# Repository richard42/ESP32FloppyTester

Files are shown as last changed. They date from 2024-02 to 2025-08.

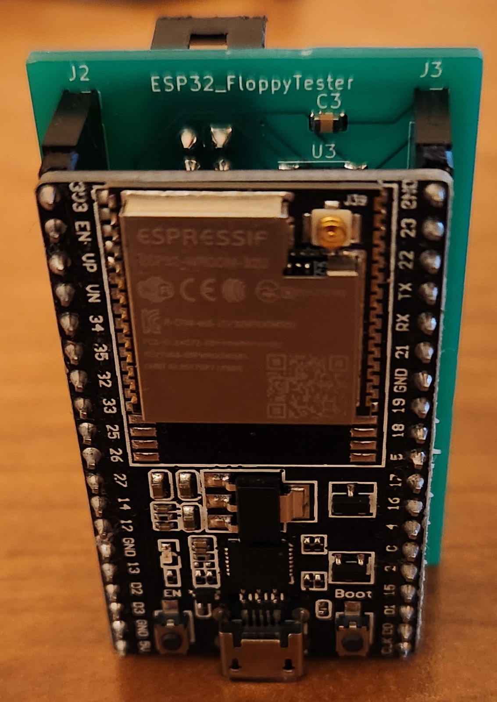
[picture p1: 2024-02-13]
doc/pic-assembled-with-esp32.jpg

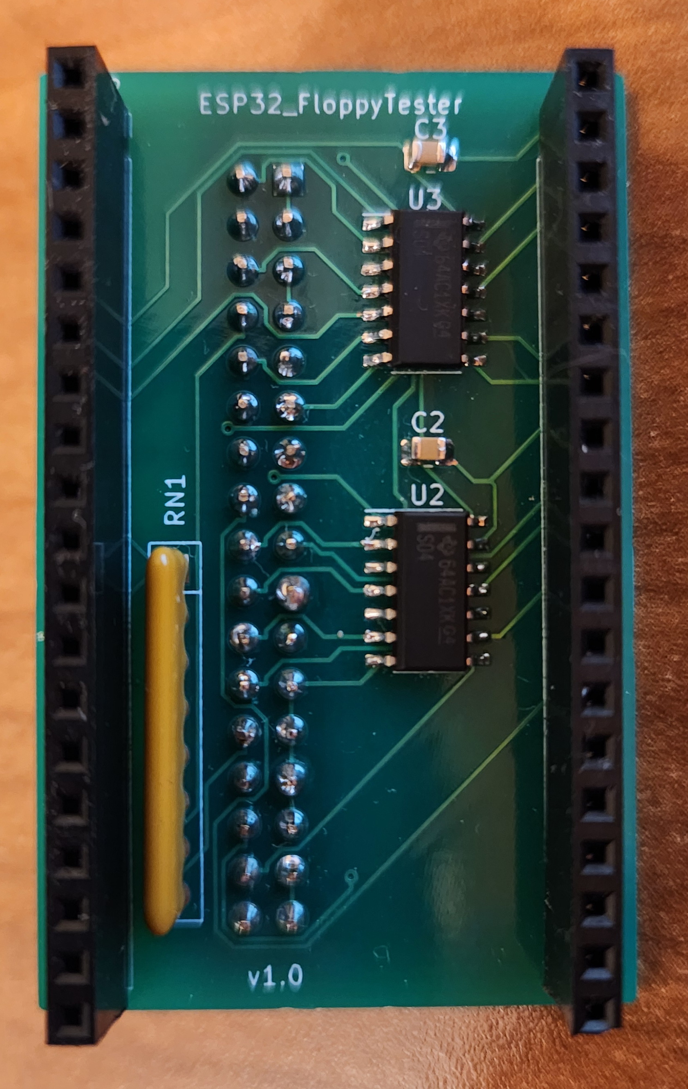
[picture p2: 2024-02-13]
doc/pic-board-front.jpg

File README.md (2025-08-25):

# ESP32_FloppyTester README

## What it is

The ESP32_FloppyTester is an open-source hardware/software project which aims to create a software-based floppy drive controller and tester with very low-cost hardware.  The materials cost for the interface board is under 10 dollars, and aside from a floppy drive cable the only other part necessary is an ESP32 development board, which can also be had for under 10 dollars.

The user communicates with the ESP32_FloppyTester via a serial monitor program on a PC or laptop, connected to the ESP32 development board by a USB cable.

The user gives commands to the ESP32_FloppyTester through the serial terminal, and as the desired operations are performed, statistics and results are sent back to the user.

The focus of this project is creating an easily-hackable tool which can be used in the diagnosis and repair of vintage 3.5" and 5.25" floppy drives.

## What it is NOT

The ESP32_FloppyTester is not designed to read or write disk image files for copying or preservation of digital media.  There are numerous projects already available which serve this function well.  Before creating the ESP32_FloppyTester, I purchased and used the KryoFlux, the FluxEngine, and the GreaseWeazle. These are all very capable products for recording and capturing data from floppy drives.

The focus of this project is to give the user very low-level control over the operation of a floppy drive so that if it is defective, the nature and root cause of the defect(s) may be determined and remedied.

## Contents

* [Hardware Warning](#hardware-warning)
* [Setup](#setup)
* [Basic Usage](#basic-usage)
* [Advanced Usage](#advanced-usage)
* [Caveats](caveats)

### Hardware Warning

There is one important flaw with the current interface board design, and users must be aware of this.

When the ESP32 microcontroller is being flashed by the ESP-IDF development system, all of its pins go into a high-impedance state with pull-up resistors.

As a result, all of the output lines will go active on any connected floppy drive. In particular, the SELECT, MOTOR ON, SIDE 1, and WRITE GATE lines will all be active during the ESP32 flashing process.

Because of this, if there is a disk inserted into the connected floppy drive, and it is not write protected, the track on side 1 which is under the drive head will be erased.

As a workaround, the user should always make sure that the drive has no disk in it when re-flashing the ESP32 software.

### Setup

To build the interface board, you may send the Gerber files in the "hardware" sub-directory to a printed-circuit board manufacturer such as PCBWay or JLCPCB. Order the remaining parts from digi-key and solder the board together once it all arrives. The "doc" sub-folder contains a Bill of Materials and pictures of the finished product.

The next step is to set up the [arduino IDE software](https://www.arduino.cc/en/software) and configure it for your ESP32 board. Then just load up the ESP32_FloppyTest.ino source code in your Arduino IDE and click the "Upload" button to compile the code and flash the ESP32 device. (But make sure there is no floppy disk in the drive, if you have one connected!)

Before connecting a drive the first time, it is good to check your soldering with the `TEST INPUT` and `TEST OUTPUT` commands.

When in the `TEST INPUT` mode, the software will poll for changes on any input pins and print the names and states of the pins when they change. You may use a jumper wire to bridge each input pin to a 5-volt supply, and observe the change via the serial monitor.

In the `TEST OUTPUT` mode, each output pin will oscillate with a binary pattern corresponding to the number of the pin. This pattern may be observed by connecting an oscilloscope to each output pin in turn. This test mode should never be used when a floppy drive is connected to the 34-pin connector, or **bad** things may happen.

Either test mode may be exited by sending a blank line or any characters to the ESP32.

### Basic Usage

Use the `HELP` command to view a list of all supported commands.

The floppy drive hardware interface, though common across many different drives and vintage computer systems, uses 5 different pins for selecting a particular drive and turning on its motor. The software currently defaults to a *shugart*-style interface with drive 0, such as would be configured for an internal drive on an Amiga computer. PC/Atari drives use different pins for drive selection, and so the user must use the `DETECT PINS` command to set the correct pins before anything else will work.

The `DETECT PINS` command activates each pin individually, and requests feedback from the user based upon how it affects the status of the floppy drive. At each step, the user must tell the ESP32_FloppyTester if the drive light has been illuminated, or if the motor has been activated. After answering all 5 prompts, the software will configure itself to properly address your floppy drive, and all of the other commands should then work.  If the detection fails and the drive light or motor never comes on, this indicates a failure in the drive's selection or motor control circuitry.

The next diagnostic step is to use the `DETECT RPM` command. A floppy disk must be inserted for this to work.  This command will enable the motor and begin sampling the INDEX pin, printing out the current drive RPM speed once per second. If this command fails, it indicates a problem with the index hole detection circuitry, or no floppy disk in the drive.

The final basic drive test can be performed with the `SEEK TEST` command. This will cause the drive to seek outwards until the TRACK0 line goes active, and then seek back and forth several times and ensure that track 0 is reached each time after returning there. If this command fails, there is likely to be a problem with the stepper motor drive circuitry or the track 0 detection mechanism.

### Advanced Usage

After all of the basic drive tests have passed, the user can move on to more advanced testing. The full command list is as follows:

```    HELP           - display this help message.
    TEST INPUT     - activate input test mode, and print level changes on input lines.
    TEST OUTPUT    - activate output test mode, and drive output pins with binary pin numbers.
    DETECT PINS    - toggle select lines to determine drive wiring/jumper setup.
    DETECT RPM     - spin up motor and calculate spindle speed from index pulses.
    DETECT STATUS  - show status of Track0, Write Protect, and Disk Change signal.
    MOTOR ON/OFF   - activate or de-activate motor 1
    SEEK HOME      - move to track 0.
    SEEK TEST      - test head seeking and track 0 detection.
    SEEK <X>       - seek head to track X.
    SEEK           - display current track number.
    SIDE <X>       - use side X (0 or 1) for single-sided commands.
    SIDE           - display current side number.
    GEOMETRY ...   - set/show current disk format and geometry. Examples:
             IBM   <SS/DS> <X> <Y> - set IBM format, single/double sided, X tracks, Y sectors.
             ATARI <SS/DS> <X> <Y> - set Atari format, single/double sided, X tracks, Y sectors.
             AMIGA                 - set Amiga format, 2 sides, 80 tracks, 11 sectors.
             COMMODORE             - set Commodore format, 1 side, 35 tracks, 17-21 sectors.
    TRACK READ     - read current track and print decoded data summary (requires formatted disk).
    TRACK ERASE    - erase current track and validate erasure (destroys data on disk).
    TRACK WRITE ...- write track data with current format and given pattern (destroys data on disk).
                ZEROS     - all sector data is binary 0 (MFM 4us intervals).
                ONES      - all sector data is binary 1 (MFM 4us intervals).
                SIXES     - all sector data is alternating bits (MFM 6us intervals).
                EIGHTS    - all sector data is alternating bits (MFM 8us intervals).
                RANDOM    - all sector data is random.
    TRACK RWTEST   - write and verify current track with 4 different patterns (destroys data on disk).\r\n");
    DISK READ      - read all tracks on disk and display track/sector status.
    DISK ERASE     - erase all tracks on the disk (destroys data on disk).
    DISK WRITE ... - write all tracks on disk with current format and given pattern (destroys data on disk).
    DISK RWTEST    - write and verify all tracks on disk with 4 different patterns (destroys data on disk).
```
#### DETECT STATUS
The `DETECT STATUS` command may be used to read the state of 3 input lines, which can indicate if the write protect switch/LED and the disk change circuitry (if supported by the drive) is working.

#### MOTOR ON
The user may activate the motor using the `MOTOR ON` command, and then the other commands will leave the motor running after they complete. This could be useful if a particular drive takes longer than the specified 0.5 seconds to settle after motor startup.

#### TRACK READ
The `TRACK READ` command captures the disk pulses from one revolution at the current head position, generates some statistics about the pulse timing intervals, and tries to decode any sector data found. This command is affected by the current drive geometry. The drive geometry must be set to "amiga" if reading amiga disks, or the default IBM if reading IBM or Atari ST disks. The output from the `TRACK READ` command looks like this:

```Track read complete; recorded 37967 flux transitions.
90% pulse interval spread is 0.7 microseconds.
Pulse Distance  Count   Average   Variance
     000004 us  18596   3.981 us  0.00324 us
     000005 us      1   4.988 us  0.00000 us
     000006 us  14598   6.025 us  0.00341 us
     000007 us      1   7.012 us  0.00000 us
     000008 us   4769   8.012 us  0.00459 us
     000030 us      1   29.712 us  0.00000 us
Double Density MFM track detected.
Found Index Access Marker (track start).
IBM Sector ID: Cylinder 0, Side 0, Sector 1, CRC=ca6f (GOOD)
IBM Sector data: 512 bytes with CRC=3cde (GOOD)
IBM Sector ID: Cylinder 0, Side 0, Sector 2, CRC=9f3c (GOOD)
IBM Sector data: 512 bytes with CRC=0f18 (GOOD)
IBM Sector ID: Cylinder 0, Side 0, Sector 3, CRC=ac0d (GOOD)
IBM Sector data: 512 bytes with CRC=b1b1 (GOOD)
IBM Sector ID: Cylinder 0, Side 0, Sector 4, CRC=359a (GOOD)
IBM Sector data: 512 bytes with CRC=0751 (GOOD)
IBM Sector ID: Cylinder 0, Side 0, Sector 5, CRC=06ab (GOOD)
IBM Sector data: 512 bytes with CRC=e9f6 (GOOD)
IBM Sector ID: Cylinder 0, Side 0, Sector 6, CRC=53f8 (GOOD)
IBM Sector data: 512 bytes with CRC=bb59 (GOOD)
IBM Sector ID: Cylinder 0, Side 0, Sector 7, CRC=60c9 (GOOD)
IBM Sector data: 512 bytes with CRC=320e (GOOD)
IBM Sector ID: Cylinder 0, Side 0, Sector 8, CRC=70f7 (GOOD)
IBM Sector data: 512 bytes with CRC=6da6 (GOOD)
IBM Sector ID: Cylinder 0, Side 0, Sector 9, CRC=43c6 (GOOD)
IBM Sector data: 512 bytes with CRC=ff82 (GOOD)
9 IBM sectors read.
```

The first line tells the total number of pulses received (flux transitions detected) during the track read. Normally, with a 720k disk this will be in the range of 15,000 to 40,000.  The data is encoded on the floppy disk by varying the time between adjacent pulses. For an MFM-encoded double-density disks, nearly all of the pulses should be either 4, 6, or 8 microseconds apart.

The "pulse interval spread" is a statistical metric which tells us how much variation exists between the pulse timings. For a formatted disk with data written along the entire track, this value will be in the 0.5-1.5 microsecond range. For a track which has been completely erased, this value will be much higher, in the 9-10 microsecond range.

Next, a histogram tells us how many pulse intervals fell into each 1-microsecond range. Again with an MFM-formatted double-density disk, we expect to see the vast majority of the pulse intervals at 4, 6, and 8 microseconds and very few in the other time ranges.

After the histogram, any decoded sector data will be printed. If you expect to see track information here, but there's nothing, and the histogram looks good, make sure that you have set the correct encoding format (IBM/Amiga) with the `GEOMETRY` command.

#### DISK READ
Using the `DISK READ` command, you can get an overview of all the sectors on the disk.  The output looks like this:

```Command> DISK READ
Found track 0 after stepping 0.0 tracks.
Reading disk sides 0 and 1.
 0 (37964 0.7) MFM  9 Sectors: OOO OOO OOO OOO OOO OOO OOO OOO OOO  |  (37911 0.7) MFM  8 Sectors: --- OOO OOO OOO OOO OOO OOO OOO OOO 
 1 (38001 0.7) MFM  8 Sectors: --- OOO OOO OOO OOO OOO OOO OOO OOO  |  (37859 0.7) MFM  8 Sectors: --- OOO OOO OOO OOO OOO OOO OOO OOO 
 2 (37856 0.7) MFM  8 Sectors: --- OOO OOO OOO OOO OOO OOO OOO OOO  |  (37846 0.7) MFM  8 Sectors: --- OOO OOO OOO OOO OOO OOO OOO OOO 
 3 (37896 0.7) MFM  8 Sectors: --- OOO OOO OOO OOO OOO OOO OOO OOO  |  (38010 0.7) MFM  8 Sectors: --- OOO OOO OOO OOO OOO OOO OOO OOO 
 4 (37953 0.7) MFM  8 Sectors: --- OOO OOO OOO OOO OOO OOO OOO OOO  |  (37851 0.7) MFM  8 Sectors: --- OOO OOO OOO OOO OOO OOO OOO OOO 
 5 (37913 0.7) MFM  8 Sectors: --- OOO OOO OOO OOO OOO OOO OOO OOO  |  (37917 0.7) MFM  8 Sectors: --- OOO OOO OOO OOO OOO OOO OOO OOO 
 6 (37851 0.7) MFM  8 Sectors: --- OOO OOO OOO OOO OOO OOO OOO OOO  |  (37865 0.7) MFM  8 Sectors: --- OOO OOO OOO OOO OOO OOO OOO OOO 
 7 (37896 0.7) MFM  8 Sectors: --- OOO OOO OOO OOO OOO OOO OOO OOO  |  (37998 0.7) MFM  8 Sectors: --- OOO OOO OOO OOO OOO OOO OOO OOO 
 8 (37863 0.7) MFM  8 Sectors: --- OOO OOO OOO OOO OOO OOO OOO OOO  |  (37900 0.7) MFM  8 Sectors: --- OOO OOO OOO OOO OOO OOO OOO OOO 
 9 (37843 0.7) MFM  8 Sectors: --- OOO OOO OOO OOO OOO OOO OOO OOO  |  (37952 0.7) MFM  8 Sectors: --- OOO OOO OOO OOO OOO OOO OOO OOO 
10 (37921 0.7) MFM  8 Sectors: --- OOO OOO OOO OOO OOO OOO OOO OOO  |  (37926 0.7) MFM  8 Sectors: --- OOO OOO OOO OOO OOO OOO OOO OOO 
11 (37910 0.7) MFM  8 Sectors: --- OOO OOO OOO OOO OOO OOO OOO OOO  |  (37894 0.7) MFM  8 Sectors: --- OOO OOO OOO OOO OOO OOO OOO OOO 
12 (37892 0.7) MFM  8 Sectors: --- OOO OOO OOO OOO OOO OOO OOO OOO  |  (37912 0.7) MFM  8 Sectors: --- OOO OOO OOO OOO OOO OOO OOO OOO 
13 (37958 0.7) MFM  8 Sectors: --- OOO OOO OOO OOO OOO OOO OOO OOO  |  (37955 0.7) MFM  8 Sectors: --- OOO OOO OOO OOO OOO OOO OOO OOO 
14 (37951 0.7) MFM  8 Sectors: --- OOO OOO OOO OOO OOO OOO OOO OOO  |  (37939 0.7) MFM  8 Sectors: --- OOO OOO OOO OOO OOO OOO OOO OOO 
15 (37899 0.7) MFM  8 Sectors: --- OOO OOO OOO OOO OOO OOO OOO OOO  |  (37882 0.7) MFM  8 Sectors: --- OOO OOO OOO OOO OOO OOO OOO OOO 
16 (37934 0.7) MFM  8 Sectors: --- OOO OOO OOO OOO OOO OOO OOO OOO  |  (37857 0.7) MFM  8 Sectors: --- OOO OOO OOO OOO OOO OOO OOO OOO 
17 (18787 10.7) MFM  0 Sectors: --- --- --- --- --- --- --- --- ---  |  (37892 2.8) MFM  0 Sectors: --- --- --- --- --- --- --- --- --- 
18 (34117 3.7) MFM  0 Sectors: --- --- --- --- --- --- --- --- ---  |  (36187 2.9) MFM  0 Sectors: --- --- --- --- --- --- --- --- --- 
```

The left half of this shows side 0, while the right half shows side 1.  At the start of each track, in parentheses, are the values for the number of flux transitions in the track, and the 90% pulse interval spread statistic.

Following this is the encoding type (MFM), the number of sectors read in the track, and 3 letters indicating the status of each sector in the track.  Three dashes or hyphens means that the sector was not detected. Otherwise, each letter is either an `O` (meaning good) or an `X` (meaning bad).

The first letter indicates whether or not the positional metadata (track number and side number) in the sector header matches with the sector's position on the disk. The second letter indicates whether the CRC or checksum value in the sector header matches with the header's actual CRC.  And the third letter indicates whether the sector's data CRC or checksum match with the checksum calculated from the data read from disk.

#### DISK RWTEST

The `DISK RWTEST` command is useful for stress testing the floppy drive and a disk to determine if it is susceptible to any particular patterns in the pulse timings.

With this command, each track is written and then read back four times, with a different data pattern each time. The first pattern uses all 4 microsecond pulse timings for the sector data. The second pattern uses all 6 microsecond pulses, and the third uses all 8 microsecond pulses.  The last data pattern starts with random sector data bytes and writes out the pulses corresponding to these random byte values.

The output of this command will look like this:

```Found track 0 after stepping 79.0 tracks.
Testing disk sides 0 and 1.
 0: OOOO OOOO OOOO OOOO OOOO OOOO OOOO OOOO OOOO | OOOO OOOO OOOO OOOO OOOO OOOO OOOO OOOO OOOO
 1: OOOO OOOO OOOO OOOO OOOO OOOO OOOO OOOO OOOO | OOOO OOOO OOOO OOOO OOOO OOOO OOOO OOOO OOOO
...
```

The leftmost number here is the track number. Then we have 4 letters for each sector, one letter for each data pattern.  If the letter is an `O`, then the data was successfully read back for that sector with that data pattern. If it is an `X`, then the sector data CRC didn't match, indicating likely data corruption. If it is an `x`, then the sector data was good but the sector header's CRC or metadata values didn't match.

### Caveats

There are many.

* This software and hardware comes with no warranty of any kind.
* Read the [Hardware Warning](#hardware-warning) again.
* Only Double Density disks are currently supported. The ESP32 is fast enough to handle HD disks as well, but it is likely that a significant amount of code refactoring would be necessary to support HD drives due to the limited amout of RAM in the ESP32.

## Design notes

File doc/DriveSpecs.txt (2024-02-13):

TEAC FD-05HF-8830 floppy drive specification:
 - Drive type:          DD/HD 3.5"
 - Input signals:       Low < 0.8v, High > 2.0v, Low sinks 0.6mA, High sinks 2uA. Internal 20k pullup.
 - Output signals:      Low < 0.3v, High > 3.7v, Low sinks up to 8mA, High sources up to 4mA
 - Rotation speed:      300 rpm
 - Start time:          480 ms
 - Step size:           2 steps per track
 - Track step time:     3 ms
 - Step settling time:  15 ms
 - Step input signal:   0.8us min pulse width
                        min interval 3ms for same direction, 4ms for changed direction
 - Write gate:          Don't enable until 18ms after last step, or 100us after SIDE1 change
                        Wait for 650us (690us DD) after de-asserting until:
                        - stopping motor
                        - pulsing step input
                        - de-asserting drive select
                        - changing SIDE1
 - Write data:          Pulse width should be between 0.2us and 1.1us
                        - Max 8us delay between data pulses and assert/de-assert WGATE
 - Read data:           Pulse width 0.15-0.8us, interval (DD) is 4us, 6us, or 8us
 - SIDE1 select:        Read Data is valid 100us after this changes
 - Track0:              Becomes valid 2.8ms after step
 - Index signal:        Is output 16-18ms after step pulse
                        - Pulse width is 1.5 to 5ms
 - 

TEAC FB-502 floppy drive specifications:
 - Drive type:          DD 5.25"
 - Input signals:       Low < 0.4v, High > 2.5v, 
 - Output signals:      Low < 0.4v, High > 2.5v, Low sinks up to 48mA

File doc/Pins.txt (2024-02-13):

FDD 34-pin      Signal      Direction   ESP32 pin   Purpose
-----------------------------------------------------------------------------
1-33 odd        Ground      <-->        GND
2               DENSEL      <---        IO32        Density selection
6               DS3         <---        IO33
8               INDEX       --->        IO4         Index hole detected (active low)
10              MOT1        <---        IO25        Run drive 1 motor
12              DS2         <---        IO23
14              DS1         <---        IO22
16              MOT2        <---        IO21
18              DIR/SIDE1   <---        IO26        Low: step to higher (inner) cylinders
20              STEP        <---        IO27        Move one cylinder step
22              WDATA       <---        IO19          Write data pulse, on falling edge
24              WGATE       <---        IO18        Low: write enable
26              TRK00       --->        IO16        Track 0 detected
28              WPT         --->        IO34        Inserted disk is write protected
30              RDATA       --->        IO35        Read data pulses, on falling edge
32              SIDE1       <---        IO17        High: select upper head 0. Low: select lower head 1
34              DISKCHG     --->        IO13        Low: no disk in drive. Must be cleared by select or seek

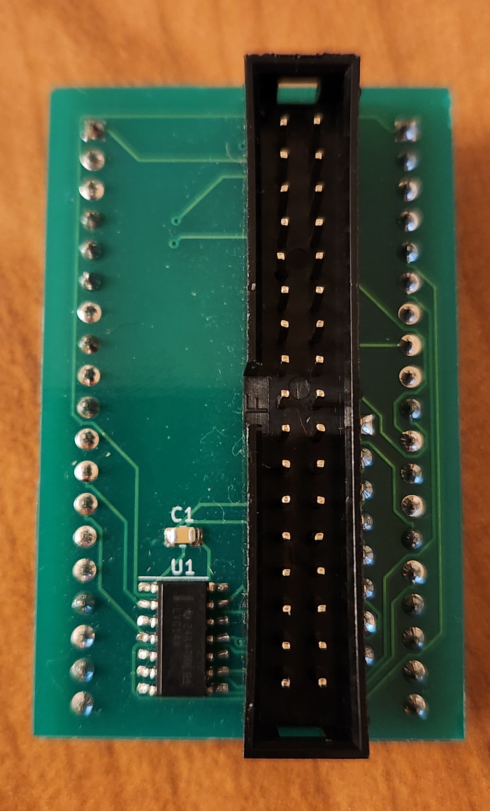
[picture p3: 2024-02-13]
doc/pic-board-back.jpg

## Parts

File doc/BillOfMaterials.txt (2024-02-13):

ESP32 Floppy Tester
Bill Of Materials
Digi-Key part numbers

Qty  P/N                     Name                                    Schematic Reference
----------------------------------------------------------------------------------------
  1  296-1699-1-ND           SN74LVC14ADR                            (U1)
  2  296-34100-5-ND          SN74S04D                                (U2, U3)
  1  4608X-101-103LF         10k resistor Array 7                    (RN1)
  3  1276-1003-1-ND          0.1uF bypass capacitor SMD 0805         (C1, C2, C3)
  1  HDR100IMP40F-G-V-TH-ND  2x19-pin female headers (cut)           (J2, J3)
  1  1528-5357-ND            34-pin IDC box header                   (J1)

* ESP32 development board is also required
 - it must have a pinout like the DevKit C board illustrated here:
   https://docs.espressif.com/projects/esp-idf/en/latest/esp32/hw-reference/esp32/get-started-devkitc.html

* PCB Component placement:
 - Top of PCB lines up with ESP32, bottom of PCB lines up with USB connector
 - J2 and J3 (19-pin female 100mil pin header sockets) insert into front of PCB
 - J1 (34-pin IDC male connector) to floppy drive cable inserts into back of PCB, with box slot to the left

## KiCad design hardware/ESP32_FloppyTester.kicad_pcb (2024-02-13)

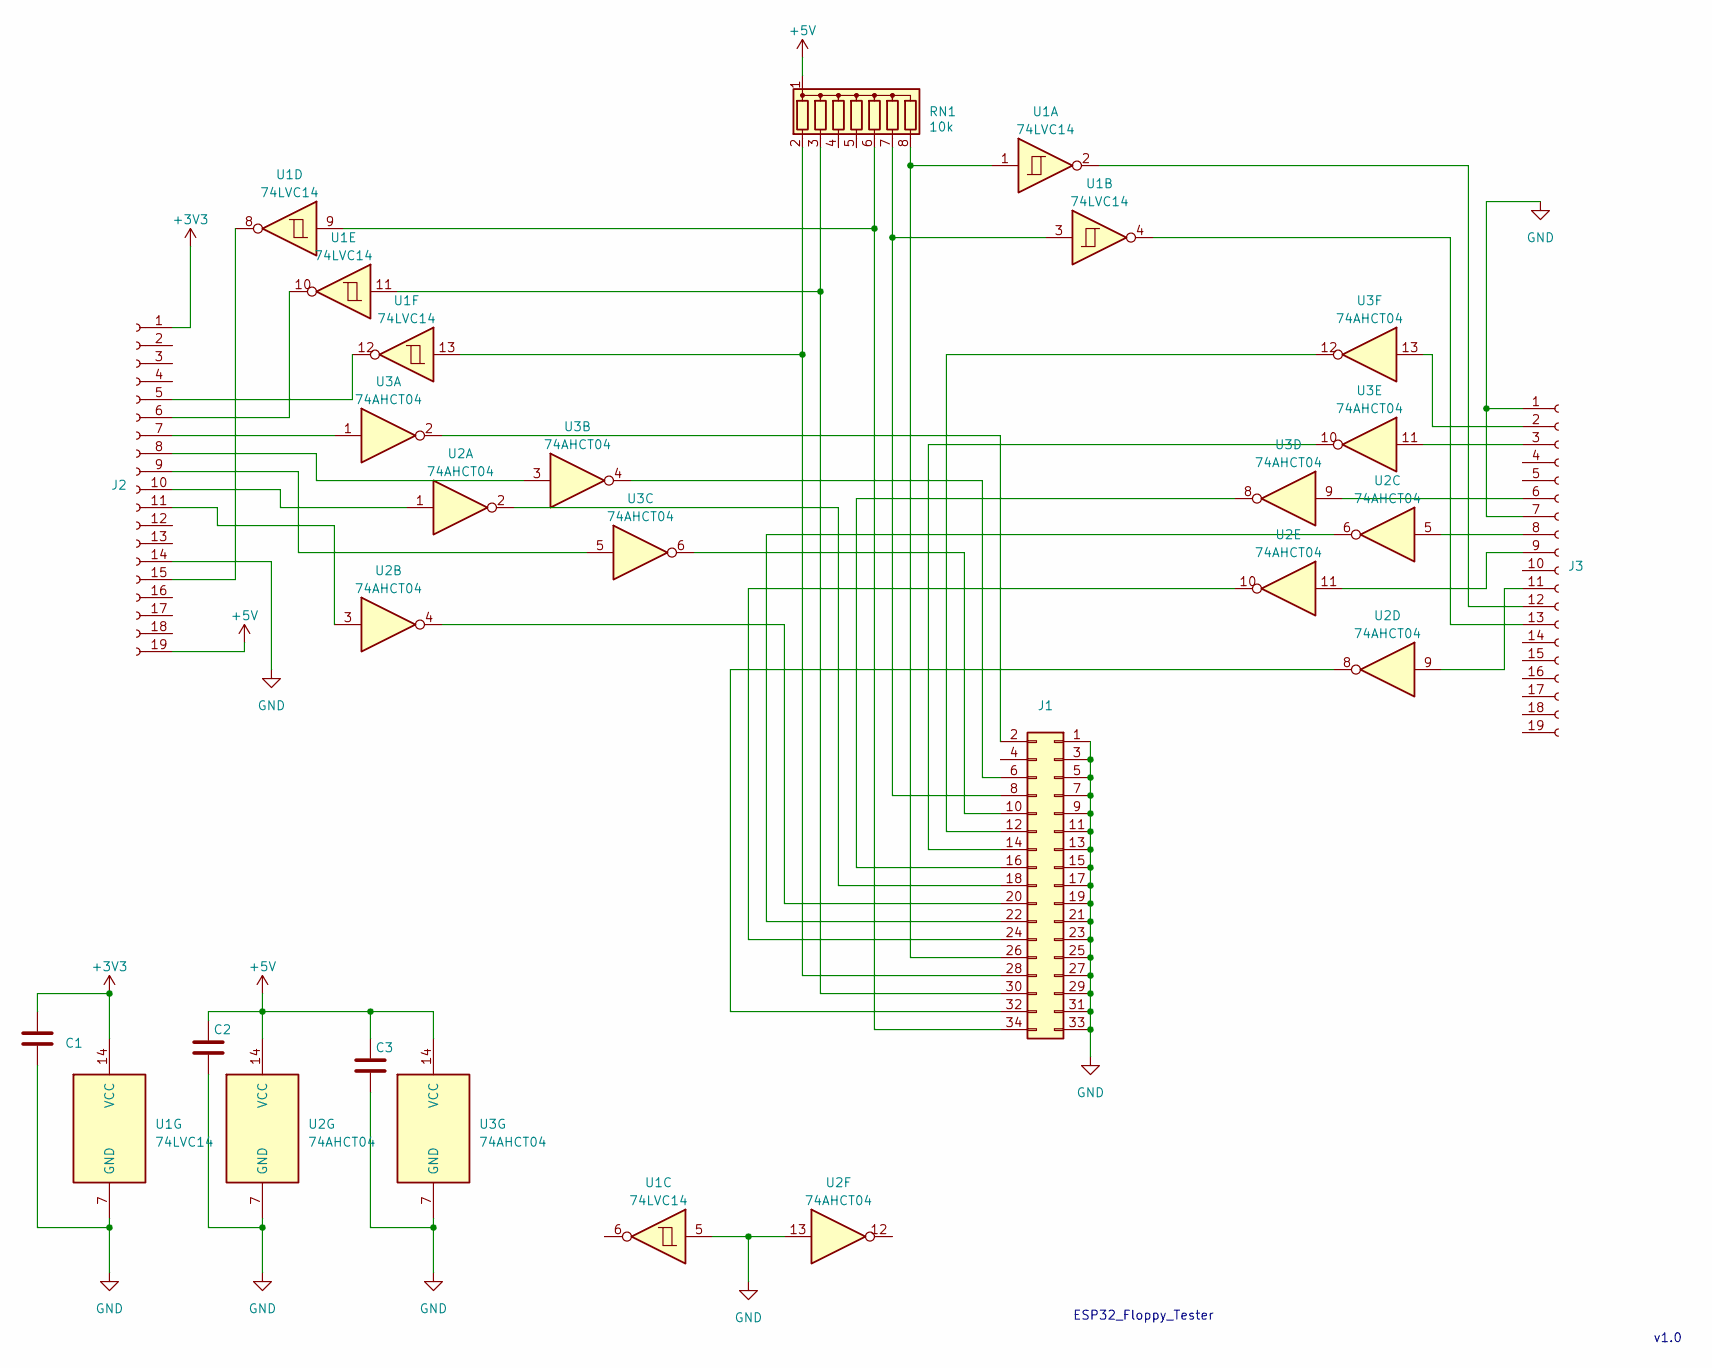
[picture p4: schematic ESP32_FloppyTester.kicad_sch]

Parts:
C1, C2, C3: 0.1uF; C_0805_2012Metric
J1: Conn_02x17_Odd_Even; PinHeader_2x17_P2.54mm_Vertical
J2, J3: Conn_01x19_Socket; PinSocket_1x19_P2.54mm_Vertical
RN1: 10k; R_Array_SIP8
U1: 74LVC14; SOIC-14_3.9x8.7mm_P1.27mm
U2, U3: 74AHCT04; SOIC-14_3.9x8.7mm_P1.27mm

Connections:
+3V3: C1.2, J2.1, U1.14 (VCC)
+5V: C2.1, C3.1, J2.19, RN1.1 (common), U2.14 (VCC), U3.14 (VCC)
GND: C1.1, C2.2, C3.2, J1.1, J1.3, J1.5, J1.7, J1.9, J1.11, J1.13, J1.15, J1.17, J1.19, J1.21, J1.23, J1.25, J1.27, J1.29, J1.31, J1.33, J2.14, J3.1, J3.7, U1.5, U1.7 (GND), U2.7 (GND), U2.13, U3.7 (GND)
unnamed: J1.2, U3.2
unnamed: J1.6, U3.4
unnamed: J1.8, RN1.7 (R6), U1.3
unnamed: J1.10, U3.6
unnamed: J1.12, U3.12
unnamed: J1.14, U3.10
unnamed: J1.16, U3.8
unnamed: J1.18, U2.2
unnamed: J1.20, U2.4
unnamed: J1.22, U2.6
unnamed: J1.24, U2.10
unnamed: J1.26, RN1.8 (R7), U1.1
unnamed: J1.28, RN1.2 (R1), U1.13
unnamed: J1.30, RN1.3 (R2), U1.11
unnamed: J1.32, U2.8
unnamed: J1.34, RN1.6 (R5), U1.9
unnamed: J2.5, U1.12
unnamed: J2.6, U1.10
unnamed: J2.7, U3.1
unnamed: J2.8, U3.3
unnamed: J2.9, U3.5
unnamed: J2.10, U2.1
unnamed: J2.11, U2.3
unnamed: J2.15, U1.8
unnamed: J3.2, U3.13
unnamed: J3.3, U3.11
unnamed: J3.6, U3.9
unnamed: J3.8, U2.5
unnamed: J3.9, U2.11
unnamed: J3.11, U2.9
unnamed: J3.12, U1.2
unnamed: J3.13, U1.4

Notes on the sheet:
ESP32_Floppy_Tester
v1.0

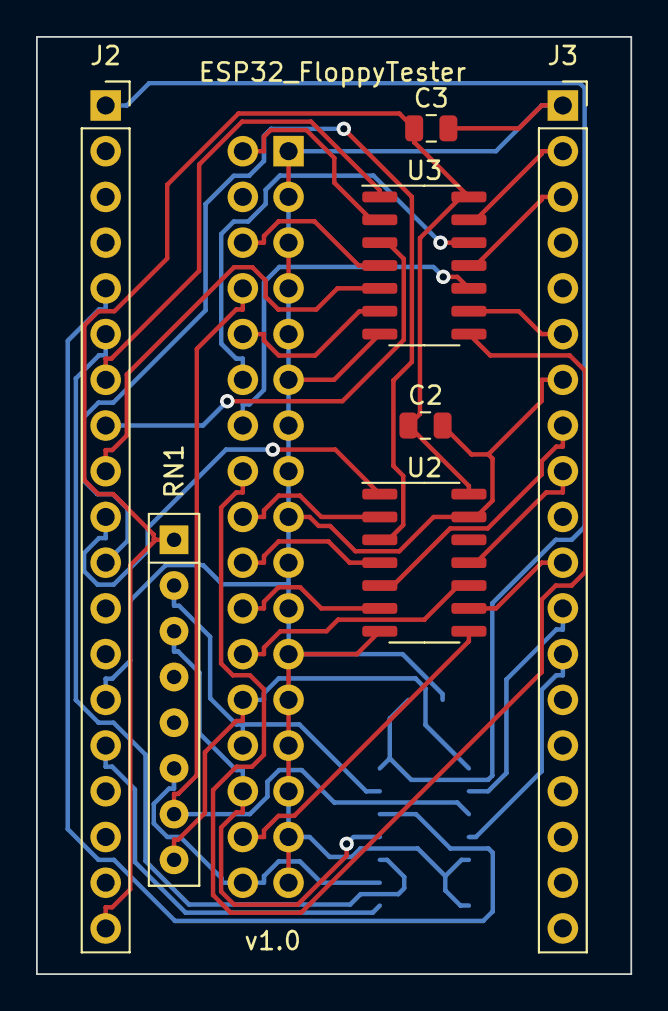
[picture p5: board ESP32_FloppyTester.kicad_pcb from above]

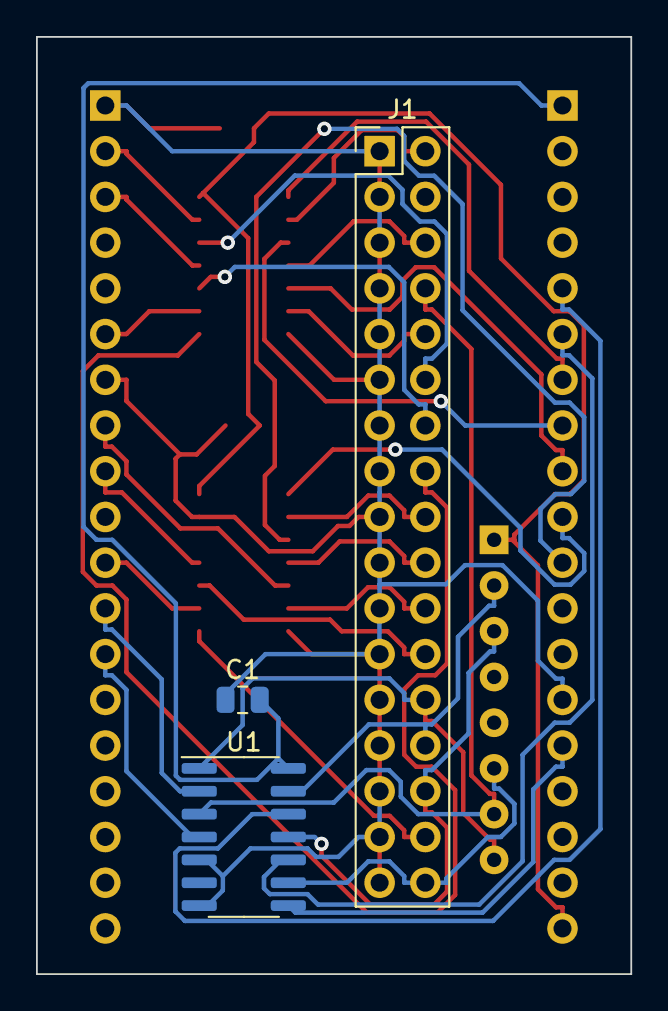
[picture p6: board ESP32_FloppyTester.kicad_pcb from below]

Board: 2 copper layers, 33.0 x 52.1 mm, 10 parts (3 on the bottom side), 35 nets.

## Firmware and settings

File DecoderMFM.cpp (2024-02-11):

//////////////////////////////////////////////////////////////////////////
// ESP32_FloppyTester
// DecoderMFM.cpp
// 
// Copyright (C) 2024, All Rights Reserved.
//
// Author: Richard Goedeken
// Date:   2024/01/28

#include <stdint.h>
#include <stdlib.h>
#include <math.h>

#include <Arduino.h>

#include <map>

#include "FloppyTester.h"
#include "DecoderMFM.h"

#define DELTA_ITEM(X) m_pusDeltaBuffers[(X)>>12][(X)&0x0fff]

//////////////////////////////////////////////////////////////////////////
// constructor and destructor

DecoderMFM::DecoderMFM(const uint16_t *pusDeltaBuffers[], uint32_t uiDeltaMax)
 : m_pusDeltaBuffers(pusDeltaBuffers)
 , m_uiDeltaMax(uiDeltaMax)
 , m_uiSectorDataLength(0)
 , m_usCurrentCRC(0xffff)
 , m_uiSectorsRead(0)
{
}

DecoderMFM::~DecoderMFM()
{
}

//////////////////////////////////////////////////////////////////////////
// accessors

//////////////////////////////////////////////////////////////////////////
// modifiers

void DecoderMFM::DecodeTrack(geo_format_t eFormat, bool bDebugPrint)
{
    // clear sector counter
    m_uiSectorsRead = 0;
    
    // iterate over all delta samples, looking for markers
    const uint8_t pucSpecialC2[] = { 3,2,3,4,3,  4,2,3,4,3,  4,2,3,4,3, 4,2,2,2,2,2,3,2 };
    const uint32_t uiSpecialC2Len = sizeof(pucSpecialC2);
    const uint8_t pucSpecialA1[] = { 3,4,3,4,3,  2,4,3,4,3,  2,4,3,4,3 };
    const uint32_t uiSpecialA1Len = sizeof(pucSpecialA1);
    const uint8_t *pucSpecMatch = NULL;
    uint32_t uiNumSpecMatch = 0;
    uint32_t uiMaxSpecMatch = 0;
    uint32_t uiFoundZeros = 0;

    for (uint32_t ui = 0; ui < m_uiDeltaMax; ui++)
    {
        // get binned time delta value and reset state if long delay is found
        uint32_t uiDelta = DELTA_ITEM(ui);
        if (uiDelta & 0x8000)
        {
            uiFoundZeros = 0;
            uiNumSpecMatch = 0;
            ui++;
            continue;
        }
        const float fWavelen = uiDelta / 80.0f;
        const uint32_t uiWavelen = floorf(fWavelen / 2.0f + 0.5f);
        // handle state
        if (uiNumSpecMatch == 0)
        {
            if (uiFoundZeros < (eFormat == FMT_AMIGA ? 12 : 80))
            {
                if (uiWavelen == 2)
                    uiFoundZeros++;
                else
                    uiFoundZeros = 0;
                continue;
            }
            if (uiWavelen == 2)
                uiFoundZeros++;
            else if (uiWavelen == 3)
                uiNumSpecMatch = 1;
            else
                uiFoundZeros = 0;
            continue;
        }
        if (uiNumSpecMatch == 1)
        {
            if (uiWavelen == 2)
            {
                pucSpecMatch = pucSpecialC2;
                uiNumSpecMatch = 2;
                uiMaxSpecMatch = uiSpecialC2Len;
            }
            else if (uiWavelen == 4)
            {
                pucSpecMatch = pucSpecialA1;
                uiNumSpecMatch = 2;
                uiMaxSpecMatch = uiSpecialA1Len;
            }
            else
            {
                uiFoundZeros = 0;
                uiNumSpecMatch = 0;
            }
            continue;
        }
        if (uiWavelen != pucSpecMatch[uiNumSpecMatch])
        {
            uiFoundZeros = 0;
            uiNumSpecMatch = 0;
            pucSpecMatch = NULL;
            continue;
        }
        uiNumSpecMatch++;
        
        // special case for Amiga
        if (eFormat == FMT_AMIGA && uiFoundZeros >= 12 && pucSpecMatch == pucSpecialA1 && uiNumSpecMatch == 10)
        {
            ui = ReadSectorBytesAmiga(ui + 1) - 1;
            continue;
        }

        // normal cases for IBM
        if (eFormat == FMT_IBM && uiNumSpecMatch == uiMaxSpecMatch)
        {
            // found a marker
            if (pucSpecMatch == pucSpecialC2)
            {
                Serial.printf("Found Index Access Marker (track start).\r\n");
                uiFoundZeros = 0;
                uiNumSpecMatch = 0;
                pucSpecMatch = NULL;
                continue;
            }
            else // (pucSpecMatch == pucSpecialA1)
            {
                ui = ReadSectorBytesIBM(ui + 1) - 1;
                continue;
            }
        }
    }

    Serial.printf("%i %s sectors read.\r\n", m_uiSectorsRead, (eFormat == FMT_IBM ? "IBM" : "Amiga"));
}

//////////////////////////////////////////////////////////////////////////
// private methods
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

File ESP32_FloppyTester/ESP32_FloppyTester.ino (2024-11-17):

//////////////////////////////////////////////////////////////////////////
// ESP32_FloppyTester
// 
// Copyright (C) 2023-2024  Richard Goedeken
//
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

#include <stdint.h>
#include <string.h>

#include <map>

#include <driver/timer.h>
#include <driver/mcpwm.h>
#include <soc/mcpwm_struct.h>
#include <soc/timer_group_struct.h>
#include <soc/timer_group_reg.h>

#include "freertos/FreeRTOS.h"
#include "freertos/task.h"
#include "freertos/xtensa_timer.h"

#include "esp_intr_alloc.h"

#include "FloppyTester.h"
#include "CodecMFM.h"
#include "CodecGCR.h"

//////////////////////////////////////////////////////////////////////////
// Definitions

#define E32FT_VERSION "1.0"

#define FDC_DENSEL   GPIO_NUM_32
#define FDC_SEL06    GPIO_NUM_33
#define FDC_INDEX    GPIO_NUM_4
#define FDC_SEL10    GPIO_NUM_25
#define FDC_SEL12    GPIO_NUM_23
#define FDC_SEL14    GPIO_NUM_22
#define FDC_SEL16    GPIO_NUM_21
#define FDC_DIR      GPIO_NUM_26
#define FDC_STEP     GPIO_NUM_27
#define FDC_WDATA    GPIO_NUM_19
#define FDC_WGATE    GPIO_NUM_18
#define FDC_TRK00    GPIO_NUM_16
#define FDC_WPT      GPIO_NUM_34
#define FDC_RDATA    GPIO_NUM_35
#define FDC_SIDE1    GPIO_NUM_17
#define FDC_DISKCHG  GPIO_NUM_13

#define TIME_MOTOR_SETTLE       500

#define CAP0_INT_EN BIT(27)  //Capture 0 interrupt bit
#define CAP1_INT_EN BIT(28)  //Capture 1 interrupt bit
#define CAP2_INT_EN BIT(29)  //Capture 2 interrupt bit

const gpio_num_t l_aiPinsInput[] = { FDC_INDEX, FDC_TRK00, FDC_WPT, FDC_RDATA, FDC_DISKCHG };
const int l_iNumInputs = sizeof(l_aiPinsInput) / sizeof(gpio_num_t);
const gpio_num_t l_aiPinsOutput[] = { FDC_DENSEL, FDC_SEL06, FDC_SEL10, FDC_SEL12, FDC_SEL14, FDC_SEL16, FDC_DIR, FDC_STEP, FDC_WDATA, FDC_WGATE, FDC_SIDE1 };
const int l_iNumOutputs = sizeof(l_aiPinsOutput) / sizeof(gpio_num_t);

int l_iPinFDDbySignal[40];

//////////////////////////////////////////////////////////////////////////
// Forward declarations

// initialization helpers
void gpio_reset(void);
void gpio_init(void);

// ISR
static void IRAM_ATTR onSignalEdge(void *pParams);

// command functions
void display_help(void);
void test_input(void);
void test_output(void);
void detect_pins(void);
void detect_rpm(void);
void detect_status(void);
bool seek_home(bool bLeaveMotorRunning = false);
void seek_test(void);
void seek_track(int iTargetTrack);
void track_read(void);
void track_erase(void);
void track_write_pattern(encoding_pattern_t ePattern);
void track_readwrite_test(void);
void disk_read(void);
void disk_erase(void);
void disk_write_pattern(encoding_pattern_t ePattern);
void disk_readwrite_test(void);

// command helpers
uint32_t format_track_metadata(int iSide, int iTrack, track_metadata_t& rsMeta, char *pchText);
void calculate_track_metadata(track_metadata_t& rsMeta);
void test_track_patterns(char *pchResults);
void capture_track_data(void);
float record_track_data(uint32_t uiDeltaMax);
float calculate_interval_spread(void);

// generic helpers
void delay_micros(uint32_t uiMicros);
std::string command_input(void);
int compare_uint32(const uint32_t *puiA, const uint32_t *puiB);

//////////////////////////////////////////////////////////////////////////
// Local variables

static bool         l_bGPIOInit = false;
static int          l_iPinSelect = FDC_SEL10;
static int          l_iPinMotor = FDC_SEL16;
static int          l_iDriveTrack = -1;
static int          l_iDriveSide = 0;
static bool         l_bDriveMotorOn = false;

static geo_format_t       l_eGeoFormat = FMT_IBM;
static int                l_iGeoSides = 2;
static int                l_iGeoTracks = 80;
static int                l_iGeoSectors = 9;

const uint32_t            cuiDeltaBufSize = 65536;
static volatile bool      l_bRecording = false;
static volatile uint32_t  l_uiLastSignalTime = 0;
static uint16_t          *l_pusDeltaBuffers[16];      // 16 * 4096 == 65536
static volatile uint16_t  l_uiDeltaPos = 0;
static volatile uint32_t  l_uiDeltaCnt = 0;

#define DELTA_ITEM(X) l_pusDeltaBuffers[(X)>>12][(X)&0x0fff]

//////////////////////////////////////////////////////////////////////////
// Initialization

void setup()
{
    // setup serial port (which internally uses UART 0)
    Serial.begin(115200);
    do {
      vTaskDelay(10);
    } while(!Serial);
    delay(200);
    Serial.write("\r\n\r\n\r\nESP32_FloppyTester v" E32FT_VERSION "  Copyright (C) 2023-2024 Richard Goedeken.\r\n");
    Serial.write("This program comes with ABSOLUTELY NO WARRANTY.\r\n");
    Serial.write("This is free software, and you are welcome to redistribute it under certain conditions.\r\n");

    // set up GPIO pins and set outputs to 0
    gpio_init();

    // allocate sample buffer memory
    //Serial.printf("Free heap memory: %i bytes\r\n", ESP.getFreeHeap());
    for (int i = 0; i < 16; i++)
    {
        l_pusDeltaBuffers[i] = (uint16_t *) malloc(8192);
        if (l_pusDeltaBuffers[i] == NULL)
        {
           Serial.printf("Error: failed to allocate delta buffer #%i/16.\r\n", i + 1);
           return;
        }
    }
    //Serial.printf("Free heap memory: %i bytes\r\n", ESP.getFreeHeap());
    
    // set up table mapping signal names to FDD connector pins (used for testing)
    memset(l_iPinFDDbySignal, 0, sizeof(l_iPinFDDbySignal));
    l_iPinFDDbySignal[FDC_DENSEL] = 2;
    l_iPinFDDbySignal[FDC_SEL06] = 6;
    l_iPinFDDbySignal[FDC_INDEX] = 8;
    l_iPinFDDbySignal[FDC_SEL10] = 10;
    l_iPinFDDbySignal[FDC_SEL12] = 12;
    l_iPinFDDbySignal[FDC_SEL14] = 14;
    l_iPinFDDbySignal[FDC_SEL16] = 16;
    l_iPinFDDbySignal[FDC_DIR] = 18;
    l_iPinFDDbySignal[FDC_STEP] = 20;
    l_iPinFDDbySignal[FDC_WDATA] = 22;
    l_iPinFDDbySignal[FDC_WGATE] = 24;
    l_iPinFDDbySignal[FDC_TRK00] = 26;
    l_iPinFDDbySignal[FDC_WPT] = 28;
    l_iPinFDDbySignal[FDC_RDATA] = 30;
    l_iPinFDDbySignal[FDC_SIDE1] = 32;
    l_iPinFDDbySignal[FDC_DISKCHG] = 34;

    // disable interrupt watchdog
    TIMERG1.wdt_wprotect = TIMG_WDT_WKEY_VALUE; // Unlock timer config.
    TIMERG1.wdt_feed = 1; // Reset feed count.
    TIMERG1.wdt_config0.en = 0; // Disable timer.
    TIMERG1.wdt_wprotect = 0; // Lock timer config.
}

void gpio_reset(void)
{
    for (int i = 0; i < l_iNumInputs; i++)
    {
        gpio_reset_pin(l_aiPinsInput[i]);
    }
    for (int i = 0; i < l_iNumOutputs; i++)
    {
        gpio_reset_pin(l_aiPinsOutput[i]);
    }
    
    l_bGPIOInit = false;
}

void gpio_init(void)
{
    // Set pin I/O modes
    for (int i = 0; i < l_iNumInputs; i++)
    {
        gpio_set_pull_mode(l_aiPinsInput[i], GPIO_FLOATING);
        gpio_set_direction(l_aiPinsInput[i], GPIO_MODE_INPUT);
    }
    for (int i = 0; i < l_iNumOutputs; i++)
    {
        gpio_set_pull_mode(l_aiPinsOutput[i], GPIO_FLOATING);
        gpio_set_level(l_aiPinsOutput[i], 0);
        gpio_set_direction(l_aiPinsOutput[i], GPIO_MODE_OUTPUT);
    }

    // we will use the MCPWM capture system to record timestamps of signal edges for the INDEX and RDATA lines
    mcpwm_gpio_init(MCPWM_UNIT_0, MCPWM_CAP_0, FDC_INDEX);
    mcpwm_gpio_init(MCPWM_UNIT_0, MCPWM_CAP_1, FDC_RDATA);

    l_bGPIOInit = true;
}

//////////////////////////////////////////////////////////////////////////
// Main loop - command processor

void loop()
{
    // put your main code here, to run repeatedly:
    Serial.write("Command> ");
    std::string strInput = command_input();

    // strip leading and trailing whitespace
    while (strInput.size() > 0 && isspace(strInput.front()))
    {
        strInput.erase(0, 1);
    }
    while (strInput.size() > 0 && isspace(strInput.back()))
    {
        strInput.pop_back();
    }
    if (strInput.size() == 0)
        return;
    
    // parse command
    if (strInput == "help")
    {
        display_help();
    }
    else if (strInput == "test input")
    {
        test_input();
    }
    else if (strInput == "test output")
    {
        test_output();
    }
    else if (strInput == "motor on")
    {
        if (l_iPinSelect == -1 || l_iPinMotor == -1)
        {
            Serial.write("Error: select/motor pin(s) not set. Use DETECT PINS\r\n");
            return;
        }
        gpio_set_level((gpio_num_t) l_iPinSelect, 1);
        gpio_set_level((gpio_num_t) l_iPinMotor, 1);
        l_bDriveMotorOn = true;
    }
    else if (strInput == "motor off")
    {
        if (l_iPinSelect == -1 || l_iPinMotor == -1)
        {
            Serial.write("Error: select/motor pin(s) not set. Use DETECT PINS\r\n");
            return;
        }
        gpio_set_level((gpio_num_t) l_iPinSelect, 0);
        gpio_set_level((gpio_num_t) l_iPinMotor, 0);
        l_bDriveMotorOn = false;
    }
    else if (strInput == "detect pins")
    {
        detect_pins();
    }
    else if (strInput == "detect rpm")
    {
        detect_rpm();
    }
    else if (strInput == "detect status")
    {
        detect_status();
    }
    else if (strInput == "geometry")
    {
        const char *pccFormat = (l_eGeoFormat == FMT_AMIGA) ? "AMIGA" : 
                                ((l_eGeoFormat == FMT_ATARI) ? "ATARI" :
                                 ((l_eGeoFormat == FMT_IBM) ? "IBM" : 
                                  ((l_eGeoFormat == FMT_C64) ? "COMMODORE" : "UNKNOWN")));
        Serial.printf("Current geometry: %s, %i sides, %i tracks, %i sectors.\r\n", pccFormat, l_iGeoSides, l_iGeoTracks, l_iGeoSectors);
    }
    else if (strInput.find("geometry ") == 0)
    {
        if (strInput == "geometry amiga")
        {
            l_eGeoFormat = FMT_AMIGA;
            l_iGeoSides = 2;
            l_iGeoTracks = 80;
            l_iGeoSectors = 11;
        }
        else if (strInput == "geometry commodore")
        {
            l_eGeoFormat = FMT_C64;
            l_iGeoSides = 1;
            l_iGeoTracks = 35;
            l_iGeoSectors = 21;
        }
        else if (strInput.find("geometry atari ") == 0)
        {
            char chSides[4] = {0, 0, 0, 0};
            int iTracks, iSectors;
            if (sscanf(strInput.c_str() + 15, "%2s %d %d", chSides, &iTracks, &iSectors) != 3)
            {
                Serial.printf("Error: invalid ATARI geometry '%s' specified.\r\n", strInput.c_str() + 15);
            }
            else if (strcmp(chSides, "ss") != 0 && strcmp(chSides, "ds") != 0)
            {
                Serial.printf("Error: invalid ATARI geometry sides '%s' specified. Must be SS or DS.\r\n", chSides);
            }
            else if (iTracks != 80 && iTracks != 81 && iTracks != 82 && iTracks != 83)
            {
                Serial.printf("Error: invalid ATARI geometry tracks '%i' specified. Must be 80-83.\r\n", iTracks);
            }
            else if (iSectors < 10 || iSectors > 11)
            {
                Serial.printf("Error: invalid ATARI geometry sectors '%i' specified. Must be 10 or 11.\r\n", iSectors);
            }
            else
            {
                l_eGeoFormat = FMT_ATARI;
                l_iGeoSides = (strcmp(chSides, "ss") == 0) ? 1 : 2;
                l_iGeoTracks = iTracks;
                l_iGeoSectors = iSectors;
            }
        }
        else if (strInput.find("geometry ibm ") == 0)
        {
            char chSides[4] = {0, 0, 0, 0};
            int iTracks, iSectors;
            if (sscanf(strInput.c_str() + 13, "%2s %d %d", chSides, &iTracks, &iSectors) != 3)
            {
                Serial.printf("Error: invalid IBM geometry '%s' specified.\r\n", strInput.c_str() + 13);
            }
            else if (strcmp(chSides, "ss") != 0 && strcmp(chSides, "ds") != 0)
            {
                Serial.printf("Error: invalid IBM geometry sides '%s' specified. Must be SS or DS.\r\n", chSides);
            }
            else if (iTracks != 35 && iTracks != 40 && iTracks != 80)
            {
                Serial.printf("Error: invalid IBM geometry tracks '%i' specified. Must be 35, 40, or 80.\r\n", iTracks);
            }
            else if (iSectors != 9 && iSectors != 18)
            {
                Serial.printf("Error: invalid IBM geometry sectors '%i' specified. Must be 9 or 18.\r\n", iSectors);
            }
            else
            {
                l_eGeoFormat = FMT_IBM;
                l_iGeoSides = (strcmp(chSides, "ss") == 0) ? 1 : 2;
                l_iGeoTracks = iTracks;
                l_iGeoSectors = iSectors;
            }
        }
        else
        {
            Serial.printf("Error: invalid geometry '%s' specified.\r\n", strInput.c_str() + 9);
        }
    }
    else if (strInput == "seek")
    {
        if (l_iDriveTrack == -1)
        {
            Serial.write("Current track position not known. You must use \"SEEK HOME\" first.\r\n");
        }
        else
        {
            Serial.printf("Current track number is %i.\r\n", l_iDriveTrack);
        }
    }
    else if (strInput.find("seek ") == 0)
    {
        if (strcmp(strInput.c_str() + 5, "home") == 0)
        {
            seek_home();
        }
        else if (strcmp(strInput.c_str() + 5, "test") == 0)
        {
            seek_test();
        }
        else
        {
            int iTargetTrack;
            if (sscanf(strInput.c_str() + 5, "%d", &iTargetTrack) != 1)
            {
                Serial.printf("Error: track number not found in command '%s'.\r\n", strInput.c_str());
                return;
            }
            if (iTargetTrack < 0 || iTargetTrack > 85)
            {
                Serial.printf("Error: invalid target track '%i' specified.\r\n", iTargetTrack);
                return;
            }
            if (l_iDriveTrack == -1)
            {
                Serial.write("Error: track position not known. You must use \"SEEK HOME\" first.\r\n");
                return;
            }
            if (l_iDriveTrack == iTargetTrack)
            {
                Serial.printf("Error: drive is already at track %i.\r\n", iTargetTrack);
                return;
            }
            seek_track(iTargetTrack);
        }
    }
    else if (strInput == "side")
    {
        Serial.printf("Current side number is %i.\r\n", l_iDriveSide);
    }
    else if (strInput.find("side ") == 0 && strInput.size() > 5)
    {
        if (strInput.at(5) == '0')
        {
            l_iDriveSide = 0;
            gpio_set_level(FDC_SIDE1, 0);
        }
        else if (strInput.at(5) == '1')
        {
            l_iDriveSide = 1;
            gpio_set_level(FDC_SIDE1, 1);
        }
        else
        {
            Serial.printf("Error: invalid SIDE selection '%s'.\r\n", strInput.at(5));
            return;
        }
    }
    else if (strInput == "track read")
    {
        track_read();
    }
    else if (strInput == "track erase")
    {
        track_erase();
    }
    else if (strInput.find("track write ") == 0)
    {
        encoding_pattern_t ePattern;
        if (strInput == "track write zeros")
            ePattern = ENC_ZEROS;
        else if (strInput == "track write ones")
            ePattern = ENC_ONES;
        else if (strInput == "track write sixes")
            ePattern = ENC_SIXES;
        else if (strInput == "track write eights")
            ePattern = ENC_EIGHTS;
        else if (strInput == "track write random")
            ePattern = ENC_RANDOM;
        else
        {
            Serial.printf("Error: invalid TRACK WRITE pattern: '%s'.\r\n", strInput.c_str() + 12);
            return;
        }
        track_write_pattern(ePattern);
    }
    else if (strInput == "track rwtest")
    {
        track_readwrite_test();
    }
    else if (strInput == "disk read")
    {
        disk_read();
    }
    else if (strInput == "disk erase")
    {
        disk_erase();
    }
    else if (strInput.find("disk write ") == 0)
    {
        encoding_pattern_t ePattern;
        if (strInput == "disk write zeros")
            ePattern = ENC_ZEROS;
        else if (strInput == "disk write ones")
            ePattern = ENC_ONES;
        else if (strInput == "disk write sixes")
            ePattern = ENC_SIXES;
        else if (strInput == "disk write eights")
            ePattern = ENC_EIGHTS;
        else if (strInput == "disk write random")
            ePattern = ENC_RANDOM;
        else
        {
            Serial.printf("Error: invalid DISK WRITE pattern: '%s'.\r\n", strInput.c_str() + 11);
            return;
        }
        disk_write_pattern(ePattern);
    }
    else if (strInput == "disk rwtest")
    {
        disk_readwrite_test();
    }
    else
    {
        Serial.write("Unknown command.\r\n");
    }
}

/////////////////////////////////////////////////////////////////////////////////////////////////////////
// Command functions

void display_help(void)
{
    Serial.write("\r\nESP32_FloppyTester commands:\r\n");
    Serial.write("    HELP           - display this help message.\r\n");
    Serial.write("    TEST INPUT     - activate input test mode, and print level changes on input lines.\r\n");
    Serial.write("    TEST OUTPUT    - activate output test mode, and drive output pins with binary pin numbers.\r\n");
    Serial.write("    DETECT PINS    - toggle select lines to determine drive wiring/jumper setup.\r\n");
    Serial.write("    DETECT RPM     - spin up motor and calculate spindle speed from index pulses.\r\n");
    Serial.write("    DETECT STATUS  - show status of Track0, Write Protect, and Disk Change signal.\r\n");
    Serial.write("    MOTOR ON/OFF   - activate or de-activate motor 1\r\n");
    Serial.write("    SEEK HOME      - move to track 0.\r\n");
    Serial.write("    SEEK TEST      - test head seeking and track 0 detection.\r\n");
    Serial.write("    SEEK <X>       - seek head to track X.\r\n");
    Serial.write("    SEEK           - display current track number.\r\n");
    Serial.write("    SIDE <X>       - use side X (0 or 1) for single-sided commands.\r\n");
    Serial.write("    SIDE           - display current side number.\r\n");
    Serial.write("    GEOMETRY ...   - set/show current drive geometry. Examples:\r\n");
    Serial.write("             IBM   <SS/DS> <X> <Y> - set IBM format, single/double sided, X tracks, Y sectors.\r\n");
    Serial.write("             ATARI <SS/DS> <X> <Y> - set Atari format, single/double sided, X tracks, Y sectors.\r\n");
    Serial.write("             AMIGA                 - set Amiga format, 2 sides, 80 tracks, 11 sectors.\r\n");
    Serial.write("             COMMODORE             - set Commodore format, 1 side, 35 tracks, 17-21 sectors.\r\n");
    Serial.write("    TRACK READ     - read current track and print decoded data summary (requires formatted disk).\r\n");
    Serial.write("    TRACK ERASE    - erase current track and validate erasure (destroys data on disk).\r\n");
    Serial.write("    TRACK WRITE ...- write track data with current format and given pattern (destroys data on disk).\r\n");
    Serial.write("                ZEROS     - all sector data is binary 0 (MFM 4us intervals).\r\n");
    Serial.write("                ONES      - all sector data is binary 1 (MFM 4us intervals).\r\n");
    Serial.write("                SIXES     - all sector data is alternating bits (MFM 6us intervals).\r\n");
    Serial.write("                EIGHTS    - all sector data is alternating bits (MFM 8us intervals).\r\n");
    Serial.write("                RANDOM    - all sector data is random.\r\n");
    Serial.write("    TRACK RWTEST   - write and verify current track 4 different patterns (destroys data on disk).\r\n");
    Serial.write("    DISK READ      - read all tracks on disk and display track/sector status.\r\n");
    Serial.write("    DISK ERASE     - erase all tracks on the disk (destroys data on disk).\r\n");
    Serial.write("    DISK WRITE ... - write all tracks on disk with current format and given pattern (destroys data on disk).\r\n");
    Serial.write("    DISK RWTEST    - write and verify all tracks on disks with 4 different patterns (destroys data on disk).\r\n");
    Serial.write("\r\n");
}

void test_input(void)
{
    // repeatedly poll the input lines and print messages for any changes
    char chLineState[l_iNumInputs];
    memset(chLineState, -1, l_iNumInputs);
    while (Serial.available() == 0)
    {
        for (int i = 0; i < l_iNumInputs; i++)
        {
            const int iESP32PinIdx = l_aiPinsInput[i];
            const int iNewState = gpio_get_level((gpio_num_t) iESP32PinIdx);
            const int iFDDPinIdx = l_iPinFDDbySignal[iESP32PinIdx];
            if (chLineState[i] != iNewState)
            {
                Serial.printf("FDD pin %i changed state to %s\r\n", iFDDPinIdx, iNewState ? "HIGH" : "LOW");
                chLineState[i] = iNewState;
            }
        }
        vTaskDelay(1);
    }
}

void test_output(void)
{
    // toggle the output lines with a 100khz pattern with 8 bits, outputting the
    // bit pattern of the pin number on each pin, until a new character is received
    // via the serial port
    while (Serial.available() == 0)
    {
        uint64_t clockTime = 0;
        timer_get_counter_value(TIMER_GROUP_0, TIMER_0, &clockTime);
        const int bitIdx = (clockTime / 100) & 7;
        const int bitTime = (clockTime % 100);
        for (int i = 0; i < l_iNumOutputs; i++)
        {
            const int iESP32PinIdx = l_aiPinsOutput[i];
            const int iFDDPinIdx = l_iPinFDDbySignal[iESP32PinIdx];
            const int iBitValue = (((iFDDPinIdx << bitIdx) & 128) && (bitTime < 90)) ? 1 : 0;
            gpio_set_level((gpio_num_t) iESP32PinIdx, iBitValue);
        }
    }
    // set all output lines low
    for (int i = 0; i < l_iNumOutputs; i++)
    {
        gpio_set_level((gpio_num_t) l_aiPinsOutput[i], 0);
    }
    // here is a much faster way to set and clear GPIO pins
    //portDISABLE_INTERRUPTS();
    //REG_WRITE(GPIO_OUT_W1TS_REG, (1 << FDC_SEL10));
    //REG_WRITE(GPIO_OUT_W1TC_REG, (1 << FDC_SEL10));
    //REG_WRITE(GPIO_OUT1_W1TS_REG, (1 << (FDC_SEL06-32)));
    //REG_WRITE(GPIO_OUT1_W1TC_REG, (1 << (FDC_SEL06-32)));
}
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

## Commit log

2024-01-22 add copyright message. add delay before printing startup prompt. use MCPWM module for capture signal edge times. add interrupt handler to record data in sample buffer. implement "test rpm" command.
2024-01-22 disable interrupt watchdog timer so that we can get extremely precise timings for disk track writes in the future. Implement extremely precise inline assembly function for adding a time delay in unit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
2024-01-23 achieve 192kb sample buffer by breaking into 12 16k buffers allocated on heap and using macro to access samples. add skeleton for "test read" command
2024-01-23 prevent seeking failures by disabling interrupts while outputting seek pulses
    [ESP32_FloppyTester.ino]
2024-01-28 bump sample buffer size up to 13 4k-sample pages. in TEST READ command, activate RDATA sampling and edge time recording during one pass between index pulses
2024-01-29 add some basic statistical analysis and track type detection in TEST READ
2024-02-06 clear interrupt bit earlier in ISR to avoid spurious interrupt calls. Add new rough draft class for parsing/decoding MFM-encoded data on IBM floppy disks
    [DecoderMFM.cpp, ESP32_FloppyTester.ino]
2024-02-06 disable FreeRTOS system timer tick interrupt while reading floppy data, or we will lose pulses
2024-02-07 code refactoring: move gpio_init/reset to top of file, break all of the command logic into separate functions, remove reset and status commands.
    [ESP32_FloppyTester.ino]
2024-02-07 rename variables and refactor logic so that if user turns on the drive motor, don't wait settling time at start of each command, and don't turn motor off at end
2024-02-08 implement DETECT STATUS command and first half of TRACK ERASE command
2024-02-09 implement second part of TRACK ERASE command. add function for calculating 90% interval spread, and display in TRACK READ also
2024-02-10 add commands to tell current track and side
2024-02-10 use format geometry when recording and parsing track data, to improve Amiga sector recognition by reading track with 10% overlap
2024-02-11 print number of tracks read. add some hacks to work around some really bad compiler bug observed in ReadSectorBytesAmiga()
    [DecoderMFM.cpp]
2024-02-11 rename loop variable in hopes of getting around compiler bug (didnt work - it still must be declared volatile)
    [DecoderMFM.cpp]
2024-02-11 fix problem which prevented Amiga MFM parser from reading first sector after the gap - it is preceded by many many zeros
    [DecoderMFM.cpp]
2024-02-11 Add TRACK WRITE command. Implement logic for writing tracks to disk with index-aligned (IBM) geometry, using CPU cycle counter. Implement EncoderMFM class with initial support for 9-sector double den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
    [DecoderMFM.cpp, ESP32_FloppyTester.ino]
2024-02-11 implement DISK READ command and helper functions for formatting metadata as text. Add code in CodecMFM to capture metadata while parsing track
2024-02-13 arduino is kind of stupid and requires the parent directory of the .ino source file to have the same name as the file without the .ino
2024-02-13 add kicad project files and output gerber files for interface board
    [ESP32_FloppyTester.kicad_pcb, ESP32_FloppyTester.kicad_sch]
2024-02-14 it is not actually necessary to decrement these track numbers outside of the loop, because there is an apparent compiler bug which keeps the loop variable at its last value before breaking the loop c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
    [ESP32_FloppyTester.ino]
2024-02-16 add new command TRACK RWTEST
2024-02-16 bugfix: when generating amiga sector data, the sector number must be 0-based, not 1-based
    [CodecMFM.cpp]
2024-02-16 bugfix: account for bit swizzling while writing an EIGHTS pattern for an Amiga disk
    [CodecMFM.cpp]
2024-11-10 in DETECT PINS, add support for Coco drives which use the same pin for both Select and Motor-on.
2024-11-15 Add new Geometry option named COMMODORE, using 1 side, 35 tracks, 21 sectors, and new FMT_C64 format. This format (like the Amiga) does not need to synchronize with the index hole. Increase maximum s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
2024-11-17 In DecoderGCR::DetectEncoding(), handle corner cases where bit patterns results in very small 2x or 3x wavelength peaks. In DecoderGCR::ReadSectorBytesC64(), allow later good sector read to overwrite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
    [CodecGCR.cpp, CodecMFM.cpp, ESP32_FloppyTester.ino]
2025-08-25 accept sector DAM values of F8-FB instead of just FB, as used on TRS-80 disks. Correctly calculate 256-byte sector data CRCs when writing MFM 18-sector formats
    [CodecMFM.cpp]

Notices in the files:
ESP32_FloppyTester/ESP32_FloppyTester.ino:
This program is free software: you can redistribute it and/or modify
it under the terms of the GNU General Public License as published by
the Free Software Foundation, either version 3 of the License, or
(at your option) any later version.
